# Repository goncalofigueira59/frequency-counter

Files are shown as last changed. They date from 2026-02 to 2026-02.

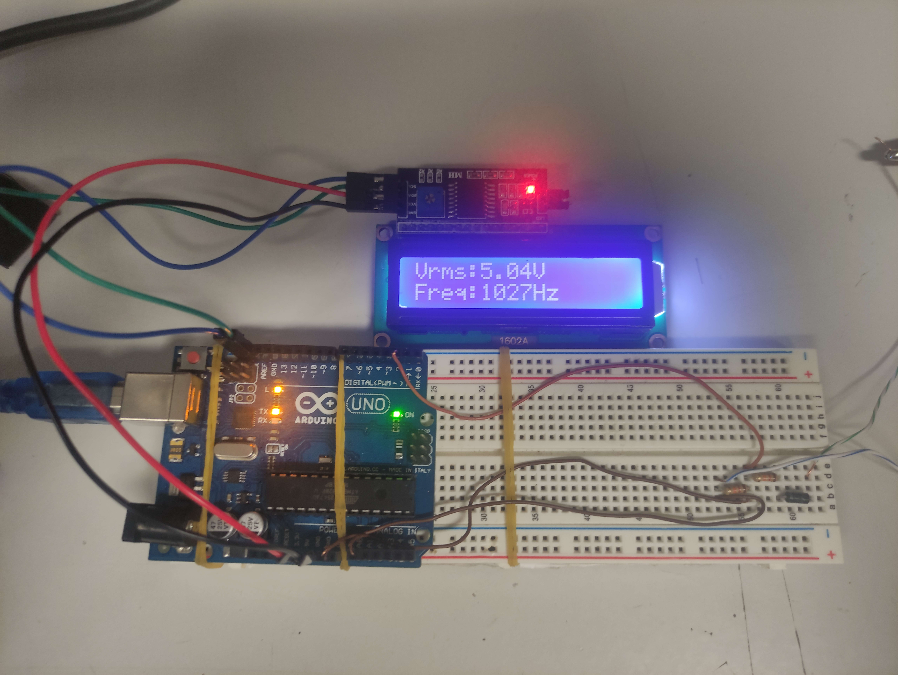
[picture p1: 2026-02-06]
assets/Protótipo Acabado.jpg

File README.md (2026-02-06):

# Frequencímetro Digital com Arduino UNO





> Frequencímetro Digital capaz de medir frequências de 1 Hz a 30 kHz e tensão RMS até 7.5V em sinais sinusoidais, triangulares e quadrados. Desenvolvido como projeto académico para a Unidade Curricular de Projeto Temático em Programação Aplicada (PTPA) da Licenciatura de Eletrónica e Mecânica Industrial da ESTGA - Universidade de Aveiro.

---

## Índice

- Funcionalidades
- Componentes Necessários
- Análise Técnica Detalhada
  - 1. Objetivo e Especificações Iniciais
  - 2. Arquitetura do Hardware
  - 3. Arquitetura do Software
  - 4. Fluxo de Operação
- Esquema Elétrico
- Resultados e Desempenho
- Conclusão e Melhorias Futuras
- Código Fonte
- Licença

---

## Visão Geral
Este projeto consistiu no desenvolvimento de um frequencímetro digital completo, integrando conhecimentos de eletrónica analógica e programação de microcontroladores. O sistema utiliza um Arduino UNO como núcleo de processamento e apresenta os resultados num display LCD 16x2 com interface I2C.

O desafio principal foi ultrapassar as especificações iniciais do enunciado (1-100 Hz) e criar um instrumento de medição robusto e preciso, implementando tanto o circuito condicionador de sinal como o firmware de aquisição e processamento de dados.

---

## Funcionalidades

- Medição de Frequência: Gama operacional de 1 Hz a 30 kHz (300× superior ao requisito inicial).
- Medição de Tensão RMS: Até 7.5V RMS (tensão de pico ~10.6V).
- Formas de Onda Suportadas: Sinusoidal, triangular e quadrada.
- Interface de Saída:** Display LCD 16x2 (via I2C) e Serial Monitor para visualização dos valores e análise em tempo real.
- Proteção de Entrada:** Condicionamento de sinal com divisor resistivo e retificação para proteção das entradas do Arduino.

---

## 🛠️ Componentes Necessários

### Hardware
| Componente | Quantidade |
| :--- | :---: |
| Arduino UNO | 1 |
| LCD 16x2 com Módulo I2C | 1 |
| Resistências 12 kΩ (±5%) | 2 |
| Diodo 1N4007 | 1 |
| Breadboard | 1 |
| Jumper Wires | ~8 |
| Gerador de Funções (TopWard 8110) | 1 |

### Software

| Ferramenta | Utilização |
| :--- | :--- |
| **Arduino IDE** | Desenvolvimento e upload do código |
| **Fritzing** | Criação do esquema elétrico |
| **GeoGebra** | Derivação da curva de calibração do ADC |

---

## Análise Técnica Detalhada

### 1. Objetivo e Especificações Iniciais
O projeto baseou-se no Projeto I da UC de Projeto Temático em Programação Aplicada. As especificações originais exigiam:
- Microcontrolador: Arduino Uno R3 (ATmega328P)
- Faixa de frequência: 1 Hz a 100 Hz
- Formas de onda: quadrada, sinusoidal e triangular
- Saída: Serial Monitor e Painel LCD

O projeto expandiu significativamente estes requisitos, focando-se na criação de um sistema completo de aquisição e condicionamento de sinal.

### 2. Arquitetura do Hardware
O circuito de condicionamento é fundamental para a precisão e segurança do sistema:
- Divisor Resistivo (1:2): Composto por duas resistências de 12 kΩ em série, reduz a amplitude do sinal de entrada para metade, permitindo medir tensões de pico até 10V mantendo-se dentro da gama de 0-5V do ADC do Arduino.
- Retificação de Meia-Onda: Um díodo 1N4007 em série remove o semiciclo negativo do sinal, protegendo o Arduino de tensões negativas e criando transições bem definidas (LOW→HIGH) essenciais para a medição de frequência por interrupção.
- Proteção: O circuito limita a corrente de entrada e previne danos ao microcontrolador.

### 3. Arquitetura do Software
O código foi estruturado modularmente para facilitar a manutenção e compreensão:

#### 3.1 Medição de Frequência (calcularFrequencia())
- Utiliza interrupções no pino digital 2 (attachInterrupt)
- A ISR ONDA0V() incrementa um contador a cada borda de subida
- A cada 1000 ms (controlado por millis()), o valor do contador é lido, resultando diretamente na frequência em Hz

#### 3.2 Medição de Tensão RMS (calcularTensao())
- Adquire 600 amostras no pino analógico A0 com intervalo de 2 ms
- Identifica o valor máximo entre as amostras
- Aplica um polinómio de calibração cúbico para compensar não-linearidades do circuito e ADC:

*_Vp_real = -0.01078·Vp³ + 0.25961·Vp² - 1.00086·Vp + 5.52515_*

- Calcula VRMS para ondas sinusoidais: Vrms = Vp_real / √2
- Inclui validações para descartar leituras com tensão insuficiente (< ~4.66V RMS)

#### 3.3 Interface e Comunicação
- Utiliza a biblioteca *_LiquidCrystal_I2C_* para controlo do display
- Envia dados paralelamente para o Serial Monitor para depuração

### 4. Fluxo de Operação
1. Inicialização (setup()): Configura comunicações (Serial, I2C), pinos e interrupção
2. Ciclo Principal (loop()): Controlado por temporizador de 1 segundo (millis())
- Desativa interrupção temporariamente
- Executa calcularTensao()
- Se tensão válida, executa calcularFrequencia()
- Atualiza display e Serial Monitor
- Reativa interrupção e reinicia contadores
3. ISR ONDA0V(): Executa assincronamente, incrementando o contador de períodos
---

## Esquema Elétrico
O circuito foi projetado e documentado utilizando a ferramenta Fritzing:
[https://github.com/seu-usuario/seu-repositorio/blob/main/esquema_frequencimetro.png?raw=true](https://github.com/goncalofigueira59/frequency-counter/blob/main/assets/Esquema_El%C3%A9trico.png)

Legenda:
- Vin: Entrada do sinal a medir
- R1, R2 (12kΩ): Divisor de tensão
- D1 (1N4007): Díodo retificador/protetor

---

## Resultados

O sistema final excedeu as especificações iniciais, apresentando os seguintes resultados:
https://github.com/goncalofigueira59/frequency-counter/blob/main/assets/Prot%C3%B3tipo%20Acabado.jpg

- **Faixa de Frequência:** 1 Hz a 30 kHz, com a Precisão de ~99.9% (sinais estáveis) aproximadamente.
- **Tensão Máxima:** 7.5V RMS (~10.6V pico)
- **Formas de Onda:** Quadrada, sinusoidal, triangular (RMS preciso apenas para sinusoidal)

Limitações identificadas:
- Cálculo RMS (Vp/√2) preciso apenas para ondas sinusoidais puras
- Resolução do ADC (10 bits) limita precisão em baixas tensões
- Circuito não mede True RMS para formas de onda complexas
---

###Conclusão e Melhorias Futuras

Este projeto serviu como integrador prático de conhecimentos em eletrónica analógica, microcontroladores e programação em C/C++. As principais lições técnicas foram a importância do condicionamento de sinal, técnicas de amostragem e temporização, e métodos de calibração de sistemas de medição.

*Possíveis melhorias técnicas futuras:*
1. Algoritmo True RMS para medição precisa em qualquer forma de onda
2. Circuito de ganho programável para maior resolução em baixas tensões e gama ampliada
3. Otimização de código:
- Deteção de pico em tempo real (sem array de 600 amostras)
- Uso de map() ou operações de bit-shift para conversão mais eficiente
4. Interface gráfica em Python com PySerial para visualização e registo de dados

---

### Código Fonte
O código completo está no repositório, no link: https://github.com/goncalofigueira59/frequency-counter/tree/main/src 

Para utilização, copie para a Arduino IDE, instale a biblioteca LiquidCrystal_I2C e carregue para o Arduino UNO.

---

## Licença

Este projeto está licenciado sob a **MIT License**. Veja o ficheiro `LICENSE` para mais detalhes.

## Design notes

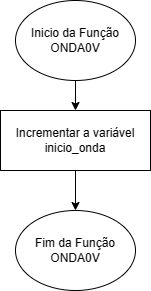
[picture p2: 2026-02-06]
assets/Fluxograma ONDA0V.png

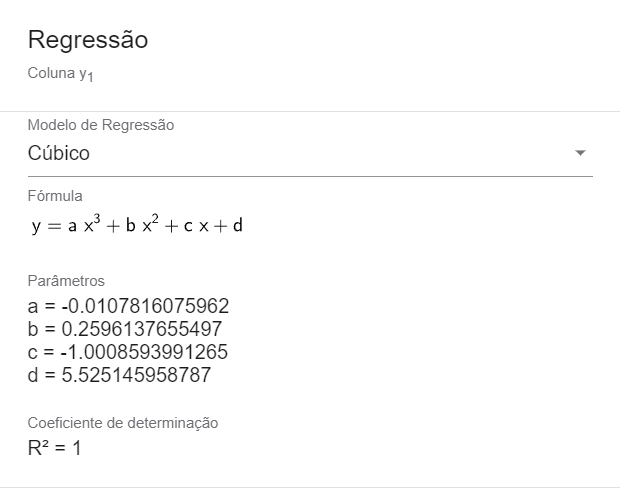
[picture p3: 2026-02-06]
assets/Expressão da Curva.png

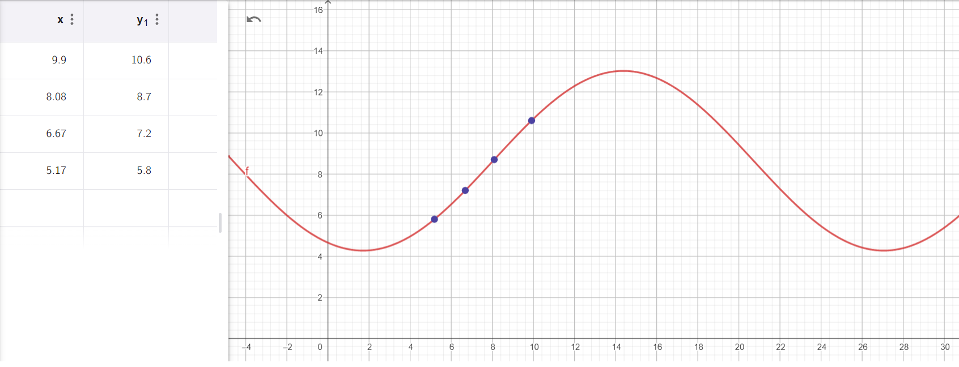
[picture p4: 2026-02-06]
Curva da Regressão.png

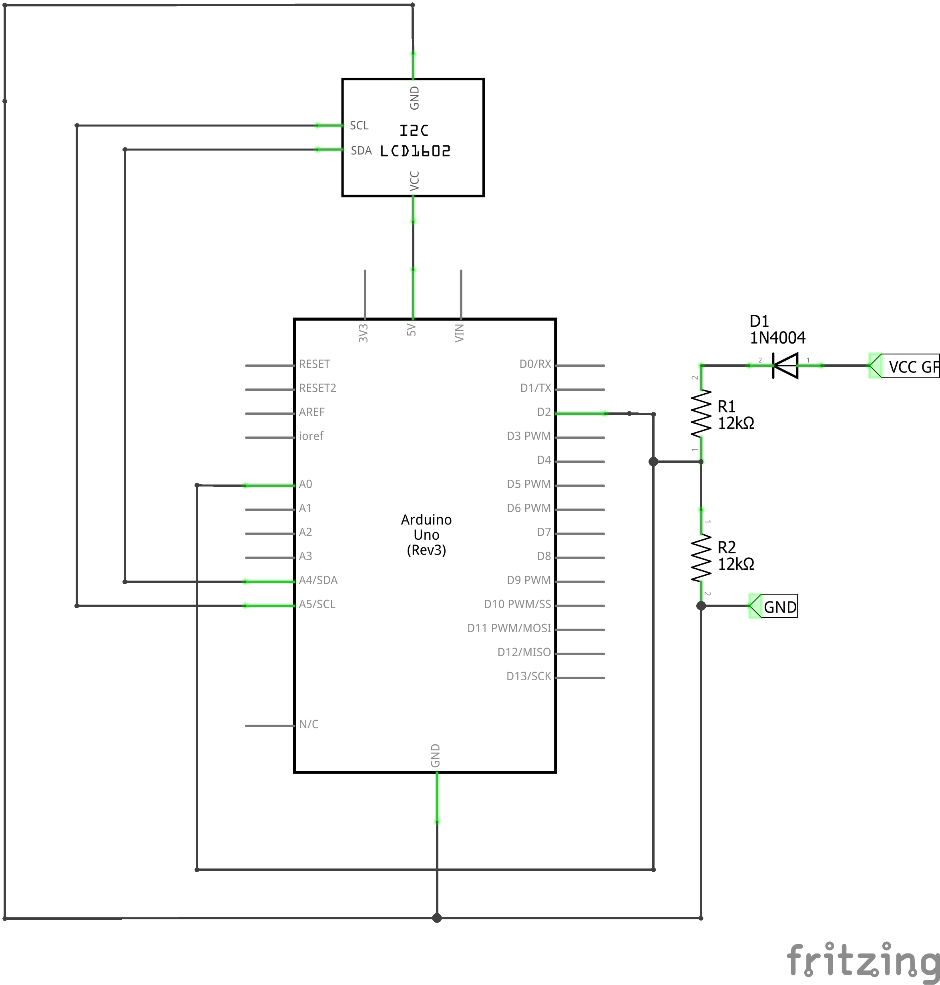
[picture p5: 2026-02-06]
assets/Esquema_Elétrico.png

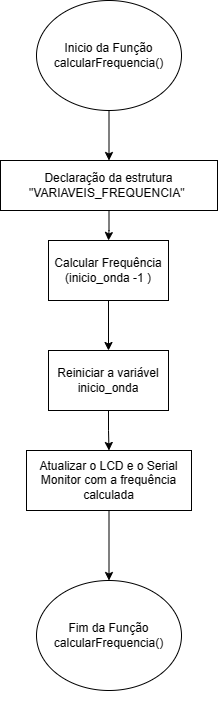
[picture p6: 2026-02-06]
assets/Fluxograma calcularFrequencia.png

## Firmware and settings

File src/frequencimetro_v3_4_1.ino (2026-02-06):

/*
           ________________________________________________________
          |  ____________________________________________________  |
          | |                                                    | |
          | |         Projeto EMI 1º ano - 1º semestre           | |
          | |               Frequencímetro V3.4.1                | |
          | |                                                    | |
          | | Autores:                                           | |
          | | - Aluno 1, 115216;                                 | |
          | | - Gonçalo Figueira, 109438;                        | |
          | | - Aluno 3, 118734;                                 | |
          | | - Aluno 4, 115154;                                 | |
          | | - Aluno 5, 119337;                                 | |
          | |                                                    | |
          | | Placa utilizada: Arduino Uno R3;                   | |
          | |____________________________________________________| |
          |________________________________________________________|

*/

#include <LiquidCrystal_I2C.h>     // Biblioteca do Display com o módulo I2C.
LiquidCrystal_I2C lcd(39, 16, 2);  // Configuração do display.

const char* mensagemTensaoInicial = "Vrms:";      //Ponteiro constante que armazena o texto "Vrms:" usado como mensagem inicial para a tensão no LCD.
const char* mensagemFrequenciaInicial = "Freq:";  //Ponteiro constante que armazena o texto "Freq:" usado como mensagem inicial para a frequência no LCD.
const char* mensagemTensaoFinal = "V ";           //Ponteiro constante que armazena o texto "V " que será projetado no LCD para assinalar o valor de tensão.
const char* mensagemFrequenciaFinal = "Hz ";      //Ponteiro constante que armazena o texto "Hz " que será projetado no LCD para assinalar o valor de frequência.

const int pinosensor = A0;    // Pino A0 que vai fazer a leitura da tensão.
const byte interruptPin = 2;  // Pino 2 que vai fazer a leitura da frequência.

int inicio_onda = 0;            // Variável que deteta o início da onda, utilizada para calcular a frequência.
long tempofrequenciafinal = 0;  // Variável que armazena o tempo da última medição.

// Estrutura para armazenar variáveis relacionadas à frequência.
typedef struct VARIAVEIS_FREQUENCIA {

  unsigned int frequencia = 0;  // Variável que retêm a frequência calculada.
};

// Estrutura para armazenar variáveis relacionadas à tensão.
typedef struct VARIAVEIS_TENSAO {

  int valorinstantaneo[600];  // Array para armazenar leituras da tensão.
  float maiorvalor;           // Variável para ler o maior valor de tensao medido pelo arduino.
  float tensaopico;           // Variável para ler a Tensão de pico.
  float tensaopicoreal;       // Variável para ler a Tensão de pico real.
  float tensaorms;            // Variável para reter o valor da Tensão eficaz (RMS).
};

void ONDA0V() {

  inicio_onda++;  //Incremento da variável inicio de onda, que serve para calcular a frequência
}

// Função para calcular frequência.
void calcularFrequencia() {

  VARIAVEIS_FREQUENCIA frequenciamedida;           // Declaração de uma estrutura para armazenar variáveis relacionadas à frequência.
  frequenciamedida.frequencia = inicio_onda - 1;   // Ajuste da contagem para obter o valor correto de ondas num intervalo de tempo
  inicio_onda = 0;                                 // Inicia a variável "inicio_onda" como zero.
  lcd.setCursor(5, 1);                             // Posiciona o cursor no LCD.
  lcd.print("         ");                          // Limpa os valores anteriores no LCD antes de imprimir novos valores.
  lcd.setCursor(5, 1);                             // Posicionamento do Cursor.
  lcd.print((String)frequenciamedida.frequencia);  // Imprime o valor da frequencia no LCD.
  lcd.print(mensagemFrequenciaFinal);              // Imprime as unidades “Hz” no LCD.
  Serial.print("Frequencia:");                     // Imprime a mensagem que indica que o valor seguinte é a Frequência.
  Serial.print(frequenciamedida.frequencia);       // Imprime o valor da frequência medida.
  Serial.println("Hz");                            // Imprime a unidade de frequência (Hz).
  Serial.println();                                // Imprime uma linha em branco para melhorar a compreensão da informação no monitor serial.
}

// Função para calcular tensão.
void calcularTensao() {

  VARIAVEIS_TENSAO tensao;  //Declaração de uma estrutura para armazenar variáveis relacionadas à tensão.

  for (int i = 0; i < 600; i++) {

    tensao.valorinstantaneo[i] = analogRead(pinosensor);  //Faz leituras da tensão com intervalos de 2 milissegundos.

    delay(2);  // Espera 2 milissegundos.
  }

  for (int i = 0; i < 600; i++) {

    tensao.maiorvalor = max(tensao.maiorvalor, tensao.valorinstantaneo[i]);  // Identifica o maior valor lido.
  }

  tensao.tensaopico = (tensao.maiorvalor * 10) / 1024;                                                                                                                        //Calcula a tensão de pico.
  tensao.tensaopicoreal = -0.0107816075962 * pow(tensao.tensaopico, 3) + 0.2596137655497 * pow(tensao.tensaopico, 2) - 1.0008593991265 * tensao.tensaopico + 5.525145958787;  //Cálculo da tensão real (tensaopicoreal) baseado na tensão de pico medida pelo Arduino (tensaopicoarduino).
  tensao.tensaorms = tensao.tensaopicoreal / sqrt(2);                                                                                                                         //Calcula o valor da tensão eficaz.

  if (tensao.maiorvalor < 1) {

    lcd.setCursor(5, 0);             // Posiciona o cursor no LCD.
    lcd.print("         ");          // Limpa os valores anteriores no LCD antes de imprimir novos valores.
    lcd.setCursor(5, 0);             // Posiciona o cursor no LCD.
    lcd.print("0");                  // Imprime o valor da tensao RMS.
    lcd.print(mensagemTensaoFinal);  // Imprime a unidade da Tensão.
    Serial.print("Tensao RMS:");     // Imprime a mensagem "Tensão RMS: " indicando que o valor seguinte é a Tensão Eficaz (RMS).
    Serial.print("0");               // Imprime o valor da Tensão RMS.
    Serial.println("V");             // Imprime a unidade de voltagem (V).
    lcd.setCursor(5, 1);             // Posiciona o cursor no LCD.
    lcd.print("         ");          // Limpa os valores anteriores no LCD antes de imprimir novos valores.
    lcd.setCursor(5, 1);             // Posiciona o cursor no LCD.
    lcd.print("V Baixa");            // Exibe no LCD a mensagem "V Baixa" quando a tensão é considerada baixa para a medição.

    Serial.print("Frequencia:");  // Imprime no monitor serial a mensagem indicando que o valor seguinte é a frequência medida.
    Serial.print("V Baixa");      // Imprime no monitor serial a informação de que a frequência está associada a uma tensão baixa.

  }

  else {

    lcd.setCursor(5, 0);     // Posiciona o cursor no LCD.
    lcd.print("         ");  // Limpa os valores anteriores do LCD antes de imprimir novos valores.
    lcd.setCursor(5, 0);     // Posiciona o cursor no LCD.

    lcd.print((String)tensao.tensaorms);  // Imprime o valor da tensao RMS.
    lcd.print(mensagemTensaoFinal);       // Imprime as unidades de Tensão.
    Serial.print("Tensao RMS:");          // Imprime a mensagem que indica que o valor seguinte é a Tensão RMS.
    Serial.print(tensao.tensaorms);       // Imprime o valor da Tensão RMS.
    Serial.println("V");                  // Imprime a unidade de voltagem (V).

    if (tensao.tensaorms < 4.66) {

      lcd.setCursor(5, 1);          // Posiciona o cursor no LCD.
      lcd.print("V Baixa");         // Imprime "V Baixa" no LCD quando a tensão é considerada baixa para a medição
      Serial.print("Frequencia:");  // Imprime no monitor serial a mensagem indicando que o valor seguinte é a frequência.
      Serial.print("V Baixa");      // Imprime no monitor serial a informação de que a frequência está associada a uma tensão baixa.
    }

    else {

      calcularFrequencia();  // Chama a função para calcular a frequência.
    }
  }
}

    // Função de Setup.
void setup() {

  Serial.begin(9600);  // Inicia a comunicação serial a uma taxa de 9600 bps.

  lcd.setBacklight(HIGH);                // Ativa o backlight (iluminação) do LCD.
  lcd.init();                            // Inicia o LCD.
  lcd.clear();                           // Limpa o conteúdo do LCD.
  lcd.setCursor(0, 0);                   // Posiciona o cursor na primeira linha e na primeira coluna do LCD.
  lcd.print(mensagemTensaoInicial);      // Imprime a mensagem inicial para a tensão no LCD.
  lcd.setCursor(0, 1);                   // Posiciona o cursor na primeira linha e na segunda coluna do LCD.
  lcd.print(mensagemFrequenciaInicial);  // Imprime a mensagem inicial para a frequência no LCD.

  pinMode(pinosensor, INPUT);                                            // Configura o pino do sensor como entrada.
  attachInterrupt(digitalPinToInterrupt(interruptPin), ONDA0V, RISING);  // Configuração da interrupção.
}

//Função de Loop.
void loop() {

  if (millis() - tempofrequenciafinal >= 1000) {

    detachInterrupt(digitalPinToInterrupt(interruptPin));  // Temporariamente desativa a interrupção para nao interferir nas leituras.

    calcularTensao();  // Chama a função para calcular a tensão.

    attachInterrupt(digitalPinToInterrupt(interruptPin), ONDA0V, RISING);  // Reativa a interrupção.

    tempofrequenciafinal = millis();  // Atualiza o tempo da última medição.
  }
}

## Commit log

2026-02-06 Escrita do documento README com análise técnica detalhada
    Revisão completa do README.md para profissionalizar a documentação do projeto.
    As principais alterações incluem:
    - Adição de uma análise técnica detalhada, baseada na documentação original do projeto.
    - Reestruturação do índice para melhor navegação.
    - Clarificação das secções de Hardware, Software e Resultados.
    - Adição de uma secção de "Conclusão e Melhorias Futuras" para dar contexto sobre os próximos passos.
2026-02-06 Curva de Regressão Matemática
2026-02-06 Expressão da Curva de Regressão Linear
2026-02-06 Ficheiro Fritzing do Esquema Elétrico
    [ESQUEMA_ELETRICO.fzz]
2026-02-06 Rename to Esq_Elet_Fritzing.fzz
    [Esq_Elet_Fritzing.fzz]
